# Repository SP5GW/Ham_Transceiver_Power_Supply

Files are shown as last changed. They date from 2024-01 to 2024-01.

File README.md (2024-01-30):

## Ham Transceiver Power Supply

<p align="center">
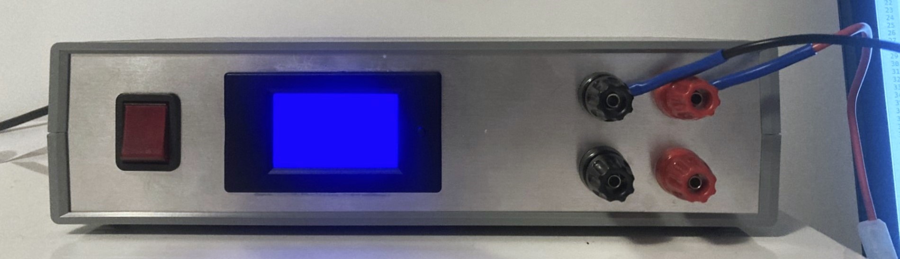
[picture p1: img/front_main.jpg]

</p> 

## Credits

*   Zygi SP5ELA for advise on what server power supply is easiest to modify
*   Patryk SP5GPK for pointing out the good quality guide describing in detail HP power supply modification steps
*   Robert DJ3KJ for excellent youtube video describing original server power supply modification
*   Krzysztof SP5OXF for suggesting Transil based overvoltage protection method

## Project Scope

This is a very simple project aiming to modify HP HSTNS-PL14 server switch-mode power supply (originally rated as 460W, 12V/38.3A) so it is capable of supplying 13.8V and about 33A of current. Additionally the power supply has been enhaced with:
*   power switch, which turns off entire unit by cutting off AC power
*   PZEM-051 based multimeter capable of measuring voltage, current, power and energy consumption
*   15V transil based overvoltage protection
*   safe chassis

## Design Details

The most difficult part of this project is to perform modification of HP HSTNS-PL14 so it is capable of producing 13.8V voltage level.
This step is very well described in youtube video [1] by Robert DJ3KJ , but due to very small size of smd components involved it requires magnification glass (or at least mobile phone with magnifying glass application) and a lot of manual skills.
In the refenernced video author suggests the following four modifications:

*   Bridging of control pins to allow power supply to start after AC power is supplied. It is very tempting to put power switch in series to the resistor, but such design is not optimal since switch placed here will not turn off entire power supply unit, leaving e.g. fun running even if power switch is off...

<p align="center">
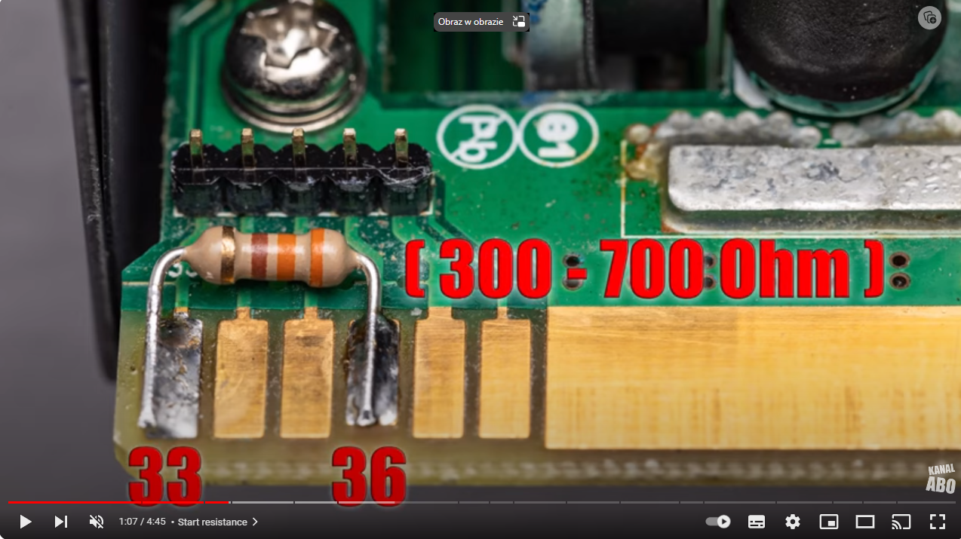
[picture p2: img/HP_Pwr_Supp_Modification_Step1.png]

</p>

*   Bridging one of SMD resistors to increse original output voltage range from 11.8-12.7 up to 13.8V 

<p align="center">
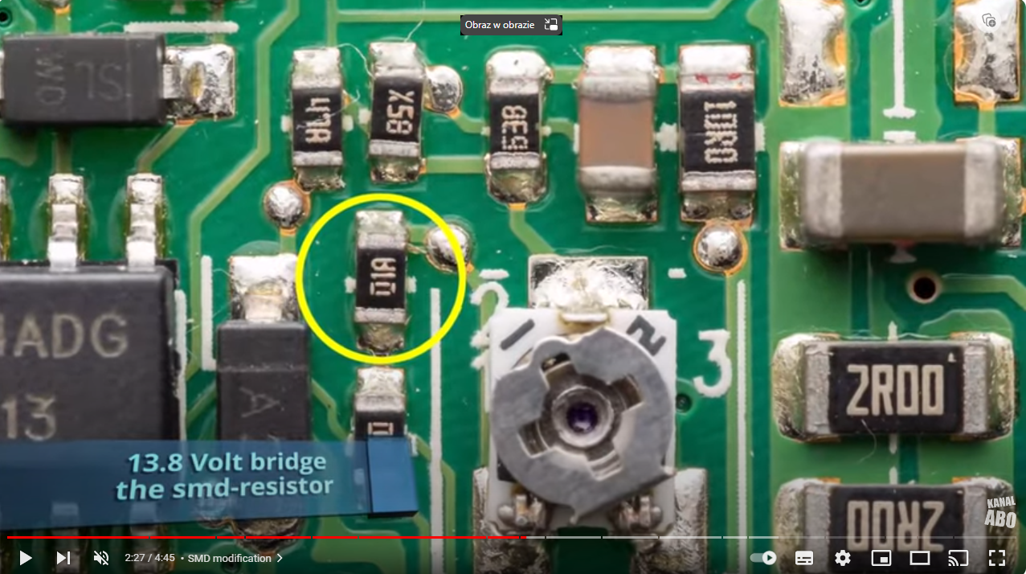
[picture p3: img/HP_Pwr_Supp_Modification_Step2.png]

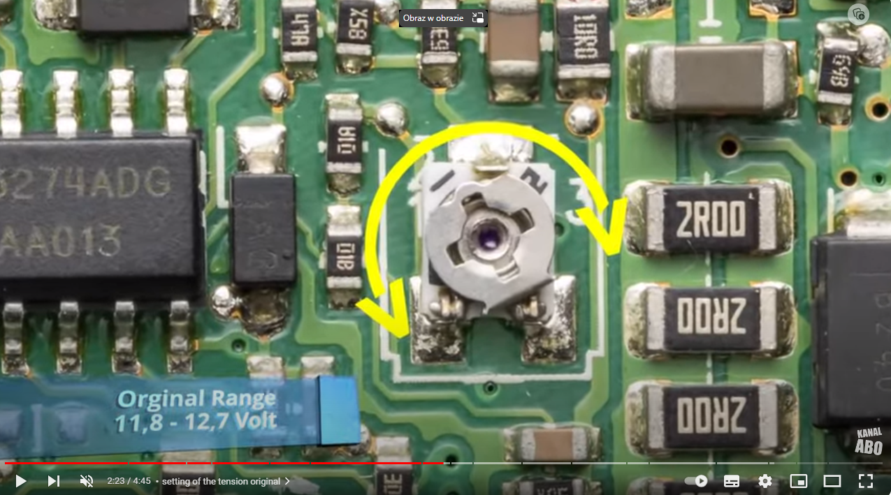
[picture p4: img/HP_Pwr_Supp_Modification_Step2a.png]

</p>

*   Adding external resistor of 5.6k as depicted on the picture below to further increase output voltage to 13.4-14V. This step did not work for me,
 i.e. adding this resistor prevented the power supply from starting up. According to original post [1] lowering external resistor value to 4.7k would increase output voltage range further to 13.9-15V, this option was not however tested by myself. 

<p align="center">
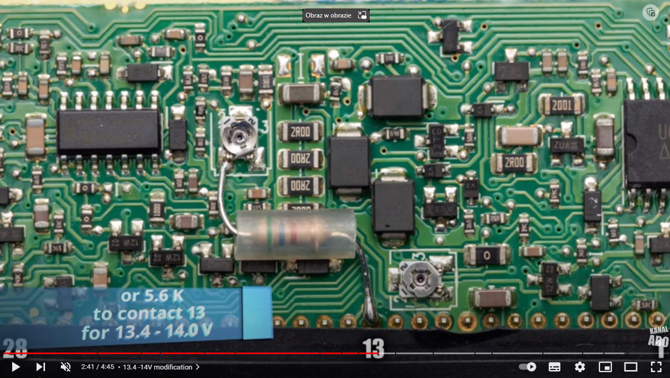
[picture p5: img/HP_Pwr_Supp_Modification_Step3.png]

</p>

*   Increase of overvoltage protection by adjusting potentiometer shown below:

<p align="center">
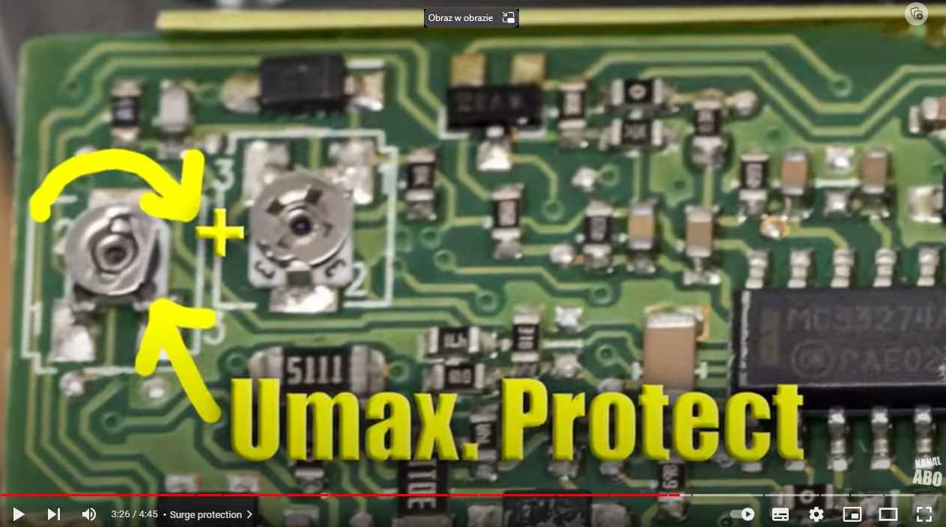
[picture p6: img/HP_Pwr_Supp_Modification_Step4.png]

</p>

High level block/circuit diagram can be found below:

<p align="center">
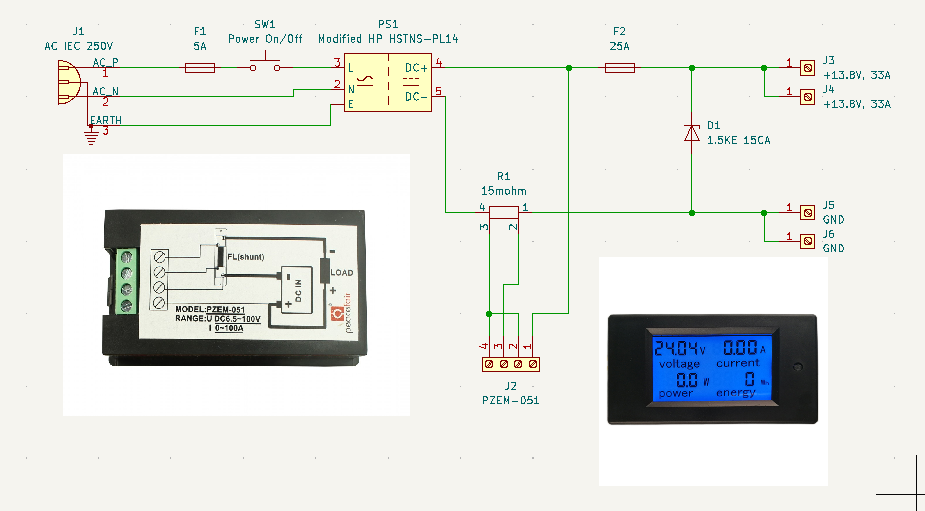
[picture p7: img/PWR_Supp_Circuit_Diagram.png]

</p>

Due to DC current of up to 33A expected at the output of power supply, all cabling is screw mounted (M4), cables used are LgY 4.00mm (except those connecting multimeter, which are LgY 0.50mm), for easy reconfiguration fork connectors clamped on the cables were used.

Bananna plugs used are 50A/60V rated (more robust version then those found in orginary equipment).

Interconnecting PZEM-051 multimeter unit is relatively easy. It is enough to follow cabling drawing on the back of the unit.

When physically mounting PZEM multimeter it is important to keep microswitch to the right of the panel.

Overvoltage protection is implemented using transil diode D1 1.5KE-15 [2]. When used as overvoltage protection, transil is connected in reverse polarity. When voltage applied  to this component is smaller then Ubr (breakdown voltage) the diode does not conduct significantly, allowing only small leakage current Ib to pass through. When voltage on the diode reaches Ubr, the diode transitions rapidly to low impedance state allowing high current Ib to pass through while stabilizing diode voltage at around Ubr and effectively clamping voltage applied to protected circuit. At this stage fuse F2 shall be blown as well.
Note that when connected in forward polarity the transil behaves as regular diode.

Mechanical design has been shown on the following pictures:

<p align="center">
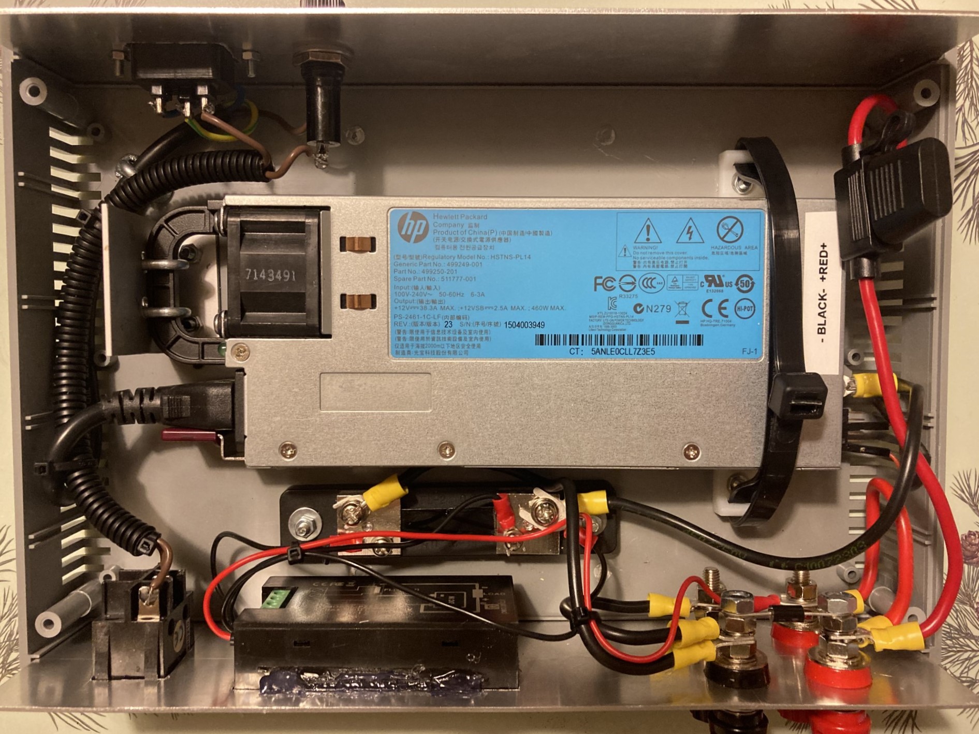
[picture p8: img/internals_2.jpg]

</p>

<p align="center">
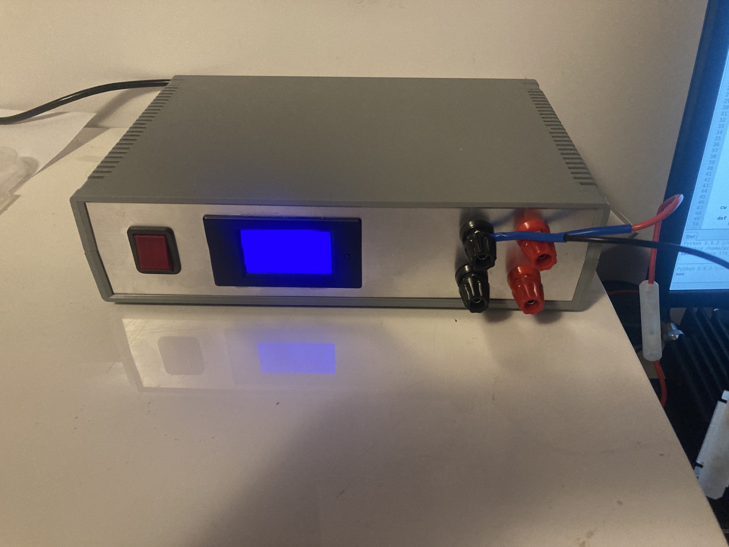
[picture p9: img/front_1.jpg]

</p>

<p align="center">
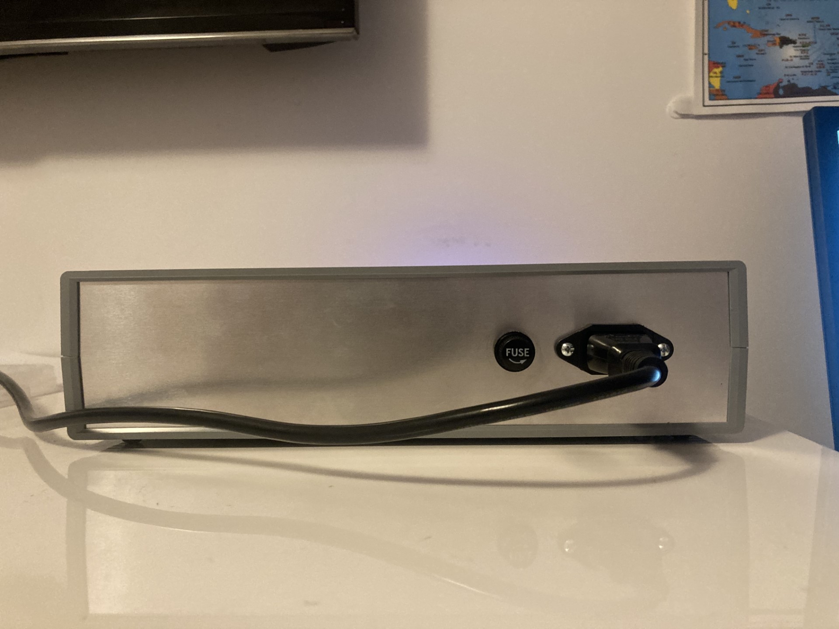
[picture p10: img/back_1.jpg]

</p>

## Transceiver Power Consumption Measurements
One application of installed multimeter is indication of both current and power consumption for by your transceiver. Summary of such measurements for my unit AnyTone AT-5888UV has been summarized below:

<p align="center">
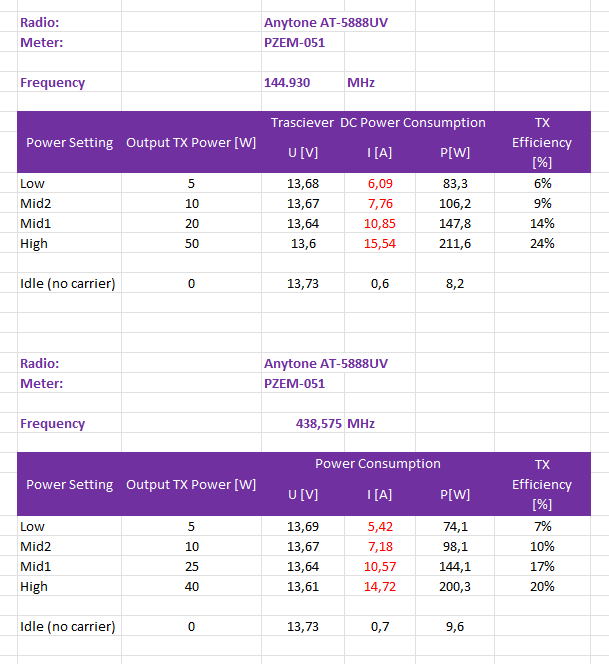
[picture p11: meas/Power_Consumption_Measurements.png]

</p>

## References

[1] HP power supply modification youtube instruction by Robert (DJ3KJ) - https://www.youtube.com/watch?v=KWyucJ1VKY4

[2] [Transil application notes](<./docs/Application_Notes/>)

[3] PZEM-051 multimeter review by Robojax - https://www.youtube.com/watch?v=tgneN2hzRe0

[4] [Hardware BoM for this project](<./docs/Power_Supply_BoM.xlsx >)

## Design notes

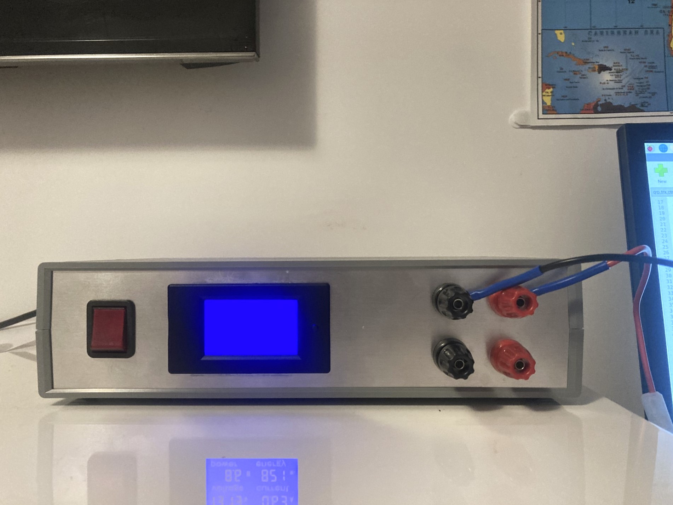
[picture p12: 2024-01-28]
img/front_3.jpg

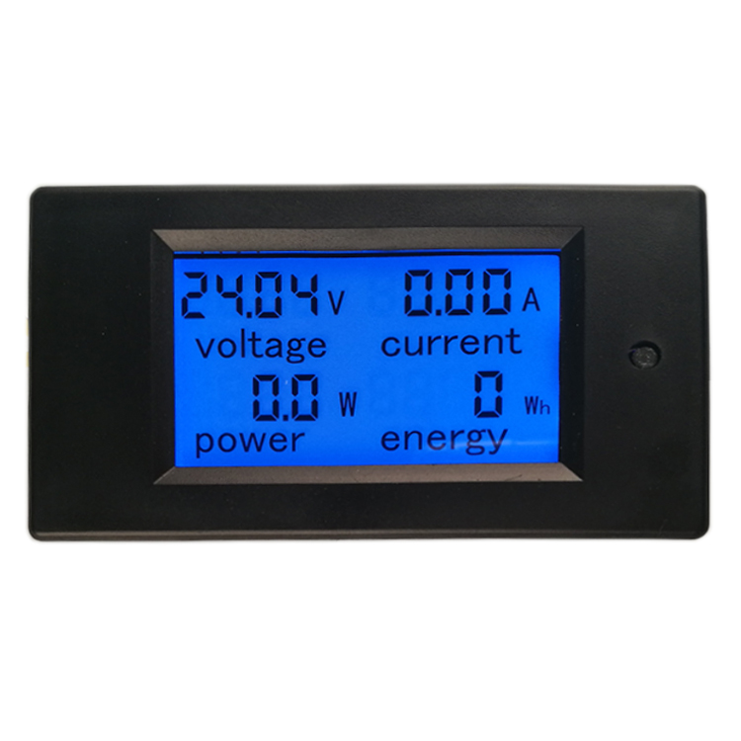
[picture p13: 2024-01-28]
img/pzem-051_front.jpg

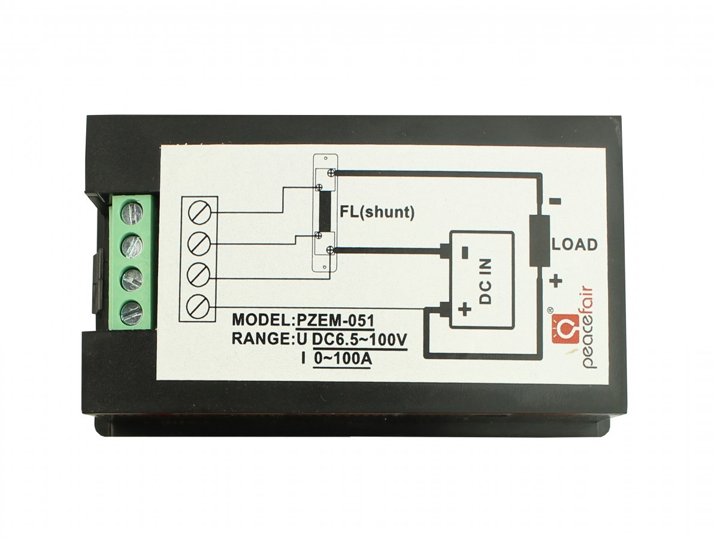
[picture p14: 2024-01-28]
img/pzem-051.jpg

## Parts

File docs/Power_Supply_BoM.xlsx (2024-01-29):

# | Product Code | Qty | Description | Seller | Unit Price [PLN] | Sub Total [PLN]
1 | HSTNS-PL14 | 1 | HP Server Power Supply | Allegro/www-getprice-pl | 74.9 | 74.9
2 |  | 1 | Chassie 300mmx200mmx75mm from ABS with aluminium front and back panel | Allegro/Typlo | 105.95 | 105.95
3 |  | 2 | Bannana Plugs AMASS 4mm 50A/60V black | Allegro/elektroniksc | 15.2 | 30.4
4 |  | 2 | Bannana Plugs AMASS 4mm 50A/60V red | Allegro/elektroniksc | 12.6 | 25.2
5 |  | 1 | cable LgY 4.00mm black, 2m | AVT | 10 | 10
6 |  | 1 | cable LgY 4.00mm black, 2m | AVT | 10 | 10
7 |  | 1 | Fork connector M6 isolated, 6.4mm, 4-6mm (pack of 10pcs) | AVT | 10 | 10
8 |  | 1 | Fork connector M6 isolated, 6.4mm, 0.5-1.5mm, SGE (pack of 10pcs) | AVT | 5 | 5
9 |  | 1 | Fork connector M4 isolated, 4.3mm, 0.5-1.5mm, SGE | AVT | 6 | 6
10 |  | 1 | Cable LgY 0.50mm, black, 1m | AVT | 5 | 5
11 |  | 1 | Cable LgY 0.50mm, red, 1m | AVT | 5 | 5
12 |  | 1 | Fuse 5A 250V 5x20mm (pack of 10pcs) | AVT | 2 | 2
13 |  | 1 | Care Fuse 25A | AVT | 2.5 | 2.5
14 |  | 1 | Fuse holder (panel mounted) fuse type 5×20 mm, 10 A 250 V, panel hole diameter 13 mm | AVT | 2.5 | 2.5
15 | 1.5KE-15 | 1 | 15V Transil (TVS diode) | vega-tronik.eu | 5 | 5
16 |  | 1 | Power Socket IEC male | vega-tronik.eu | 10 | 10
17 |  | 1 | Car fuse holder 30A | AVT | 6.8 | 6.8
18 | PZEM-051 | 1 | Panel mounted multimeter | Amazon | 53.19 | 53.19
19 |  | 1 | Resistor, 470ohm | AVT |  | 0
20 | RS210 | 1 | Panel mounted power switch 10A/250V (MARQUARDT) | vega-tronik.eu | 12.5 | 12.5
 |  |  |  |  |  | 381.94

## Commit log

2024-01-28 circuit diagram added
    [Integration_Diagram_Ham_Transceiver_Power_Supply.kicad_sch]
2024-01-28 measurements section added
    [Transceiver_PWR_Consumption_Transil_Meas.xlsx]
2024-01-29 readme further updated
    [Transceiver_PWR_Consumption_Transil_Meas.xlsx]
2024-01-29 BoM document added
    [Power_Supply_BoM.xlsx]
2024-01-30 BoM added to readme
